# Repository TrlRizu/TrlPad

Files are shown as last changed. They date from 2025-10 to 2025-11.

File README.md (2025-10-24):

# TrlPad

TrlPad is a 4-key macropad with a rotary encoder, an OLED display.

## Features

- 4 programmable mechanical keys (MX-style switches)
- Rotary encoder with push-button for multi-function input
- 0.91" 128x32 OLED dispvlay (SSD1306)
- Powered by Seeed Studio XIAO nRF52840 (Bluetooth + USB)
- Custom PCB

## How it evolved

### The initial concept
The design concept was to be something akin to a pedal effect. A sketch of what I thought it'd be:



### Final
Yeah, it's rather different but this is more feasible and it's simple yet punk-y.



### PCB
Below is the schematic:

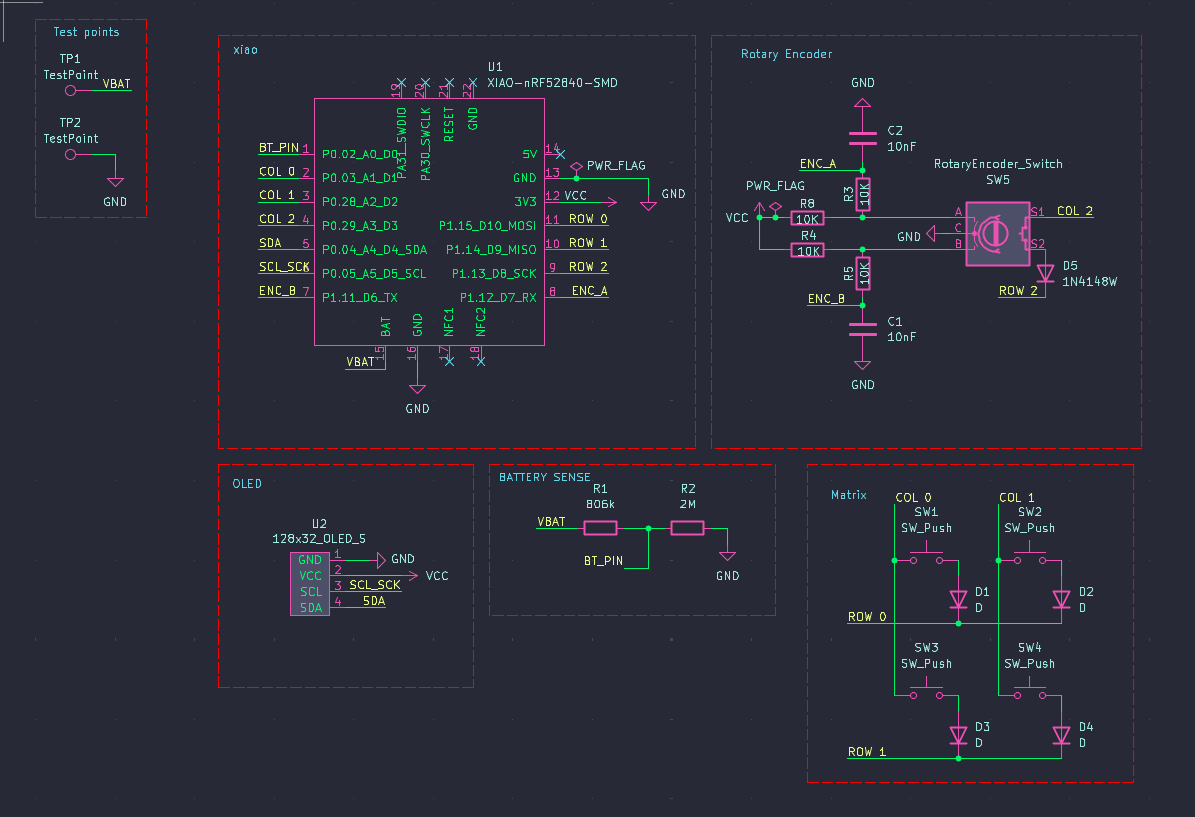
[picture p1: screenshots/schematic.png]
Schematic


Below is the PCB routing:

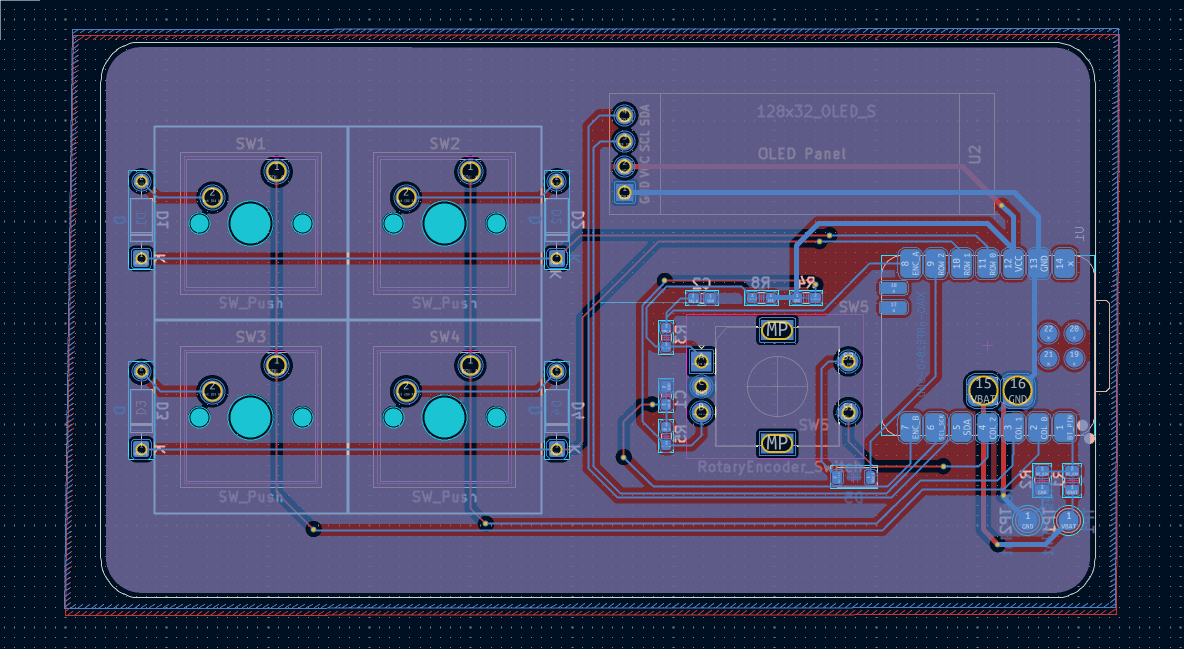
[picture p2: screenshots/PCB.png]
routing

---

## Bill of Materials (BOM)

| #  | Reference | Value | Footprint | Qty | Link | Price (USD) | Running Price (USD) |
|----|---|---|---|-----|---|---|---|
| 1  | D1, D2, D3, D4 | D | Diode_THT:D_DO-35_SOD27_P7.62mm_Horizontal | 4 | [AliExpress](https://www.aliexpress.com/item/1005007625866819.html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) | 1.41 | 1.41 |
| 2  | D5 | 1N4148W | Diode_SMD:D_SOD-123 | 1 | [AliExpress](https://www.aliexpress.com/item/1005007160279747.html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) | 1.95 | 3.36 |
| 3  | R1 | 806k | Resistor_SMD:R_0805_2012Metric | 1 | [AliExpress](https://www.aliexpress.com/item/1005008964311488.html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) | 0.66 | 4.50 |
| 4  | R2 | 2M | Resistor_SMD:R_0805_2012Metric | 1 | [AliExpress](https://www.aliexpress.com/item/1005008964311488.html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) | 0.48 | 4.50 |
| 5  | SW1, SW2, SW3, SW4 | SW_Push | Button_Switch_Keyboard:SW_Cherry_MX_1.00u_PCB  | 4 | [AliExpress](https://www.aliexpress.com/item/1005006255961111.html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) | 1.01 | 5.51 |
| 6  | SW5 | RotaryEncoder_Switch | Rotary_Encoder:RotaryEncoder_Alps_EC11E-Switch_Vertical_H20mm | 1 | [AliExpress](https://www.aliexpress.com/item/1005006693443387.html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) | 0.63 | 6.14 |
| 7  | TP1, TP2 | TestPoint | TestPoint:TestPoint_Pad_D2.0mm | 2 | — | — | 6.14 |
| 8  | U1 | XIAO-nRF52840-SMD  | Modified:modified-XIAO-nRF52840-SMD | 1 | [AliExpress](https://www.aliexpress.com/item/1005006988954136.html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) | 10.11 | 16.25 |
| 9  | U2 | 128x32_OLED_S | zzz_Project:SSD1306-0.91-OLED-4pin-128x32 | 1 | [AliExpress](https://www.aliexpress.com/item/1005008640132638.html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) | 2.24 | 18.49 |
| 10 | Shipping costs  | — | for AliExpress check cart.png | — | — | 3.05 | 21.54 |
| 11 | 3D Printed case | — | check screenshot 3dCase_bill.png | — | [3Ding](https://print.3ding.in/upload) | 16.29 | 37.83 |
| 12 | PCB | — | from JLPCB, check screenshot jlcpcb.png | — | — | 7.56 | 45.39 |

**Total Estimated Cost:** 45.39 USD

####  Note: I am trying to get the case 3D printed using #printing-legion, or if that doesn't work out, I'll cover the cost on my own!
---

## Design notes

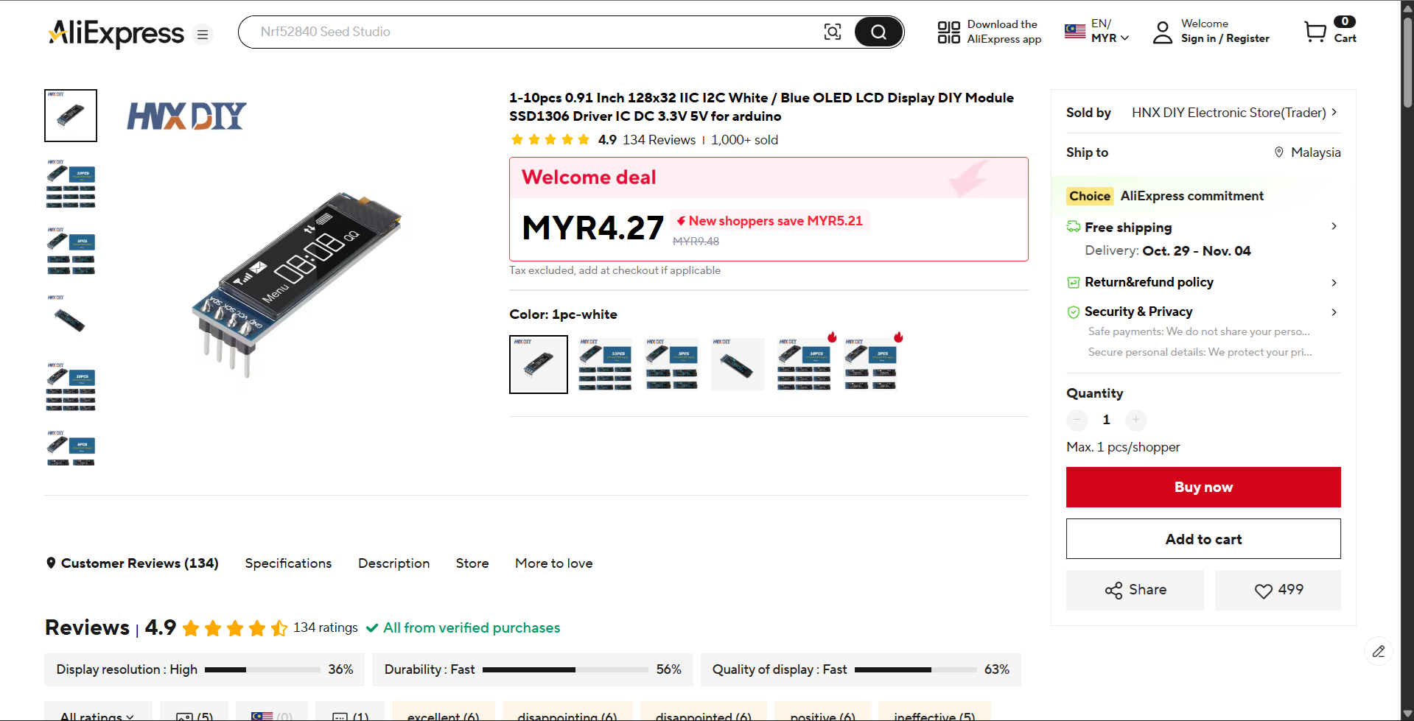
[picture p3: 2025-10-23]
screenshots/oled.png

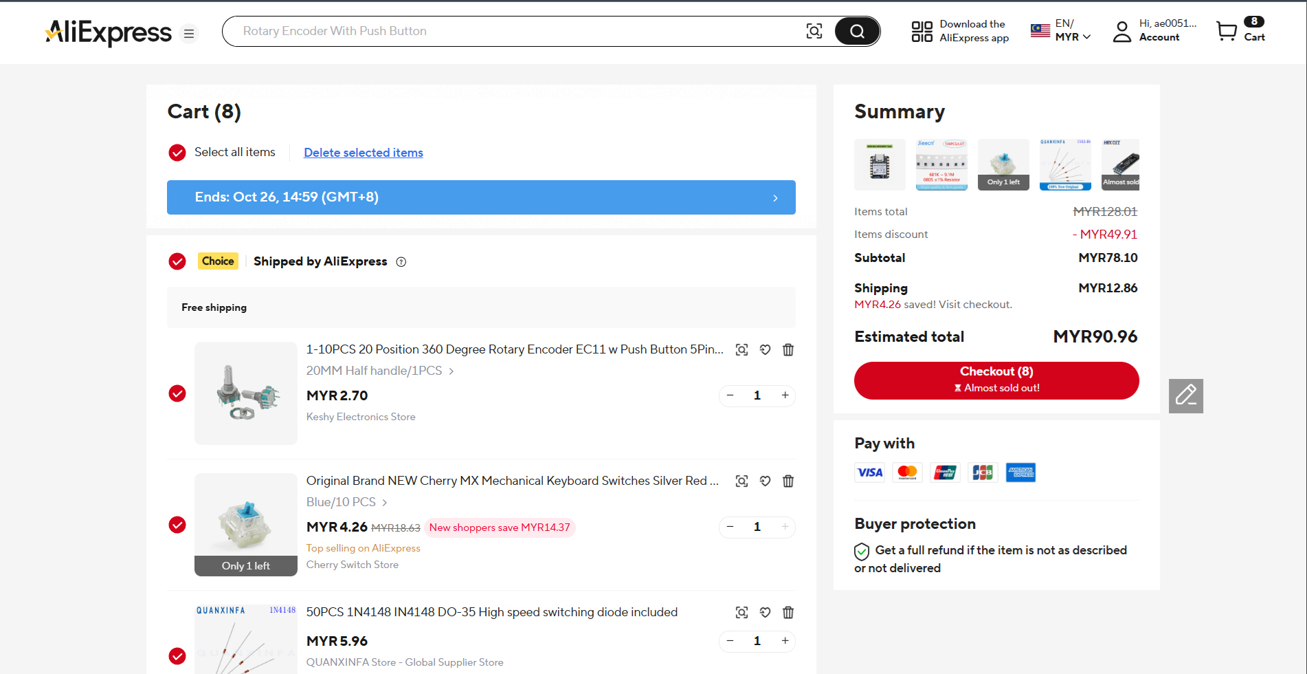
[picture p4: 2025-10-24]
screenshots/cart.png

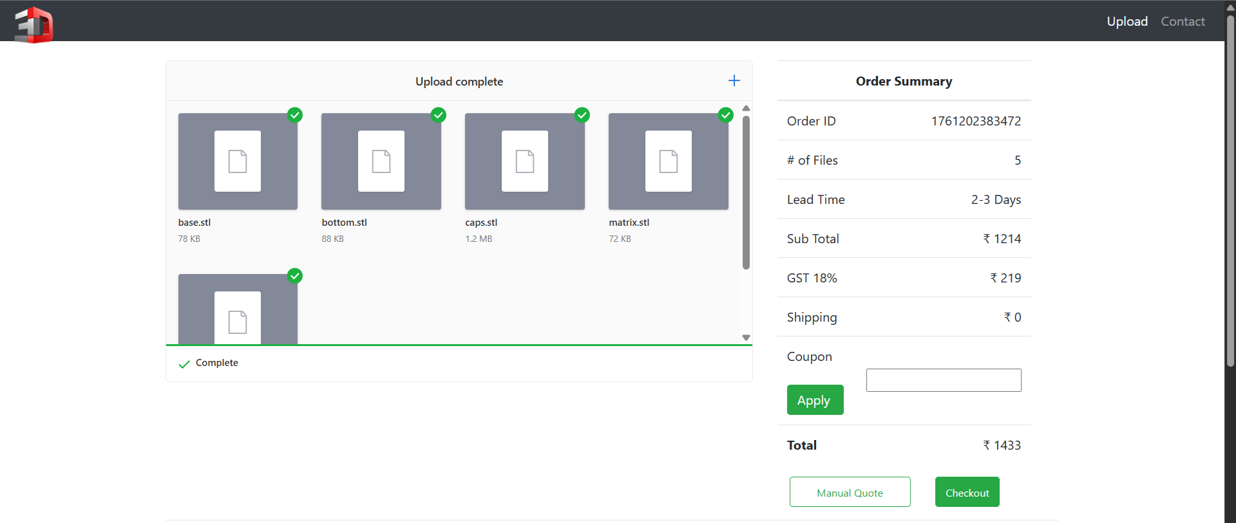
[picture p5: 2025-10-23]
screenshots/3dCase_bill.png

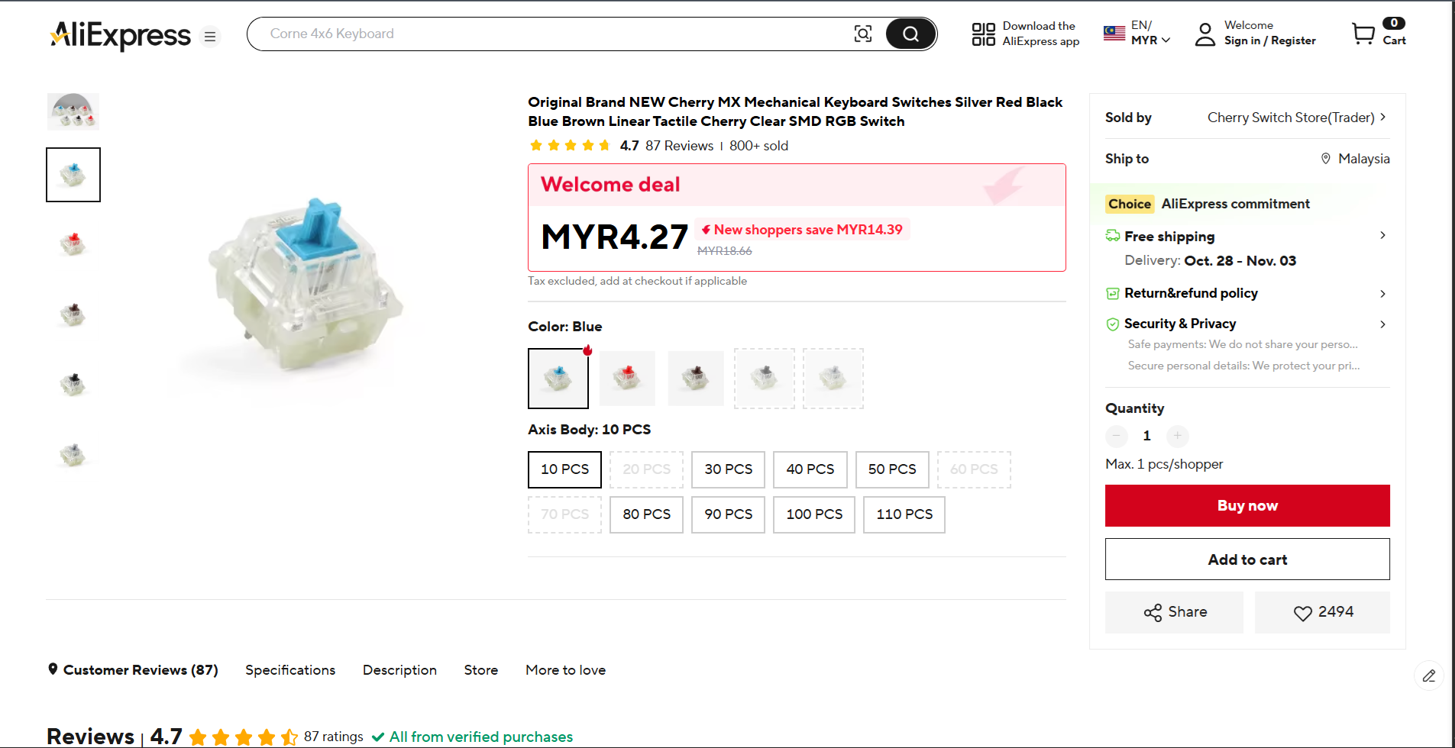
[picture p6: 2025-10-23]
screenshots/cherry-mx.png

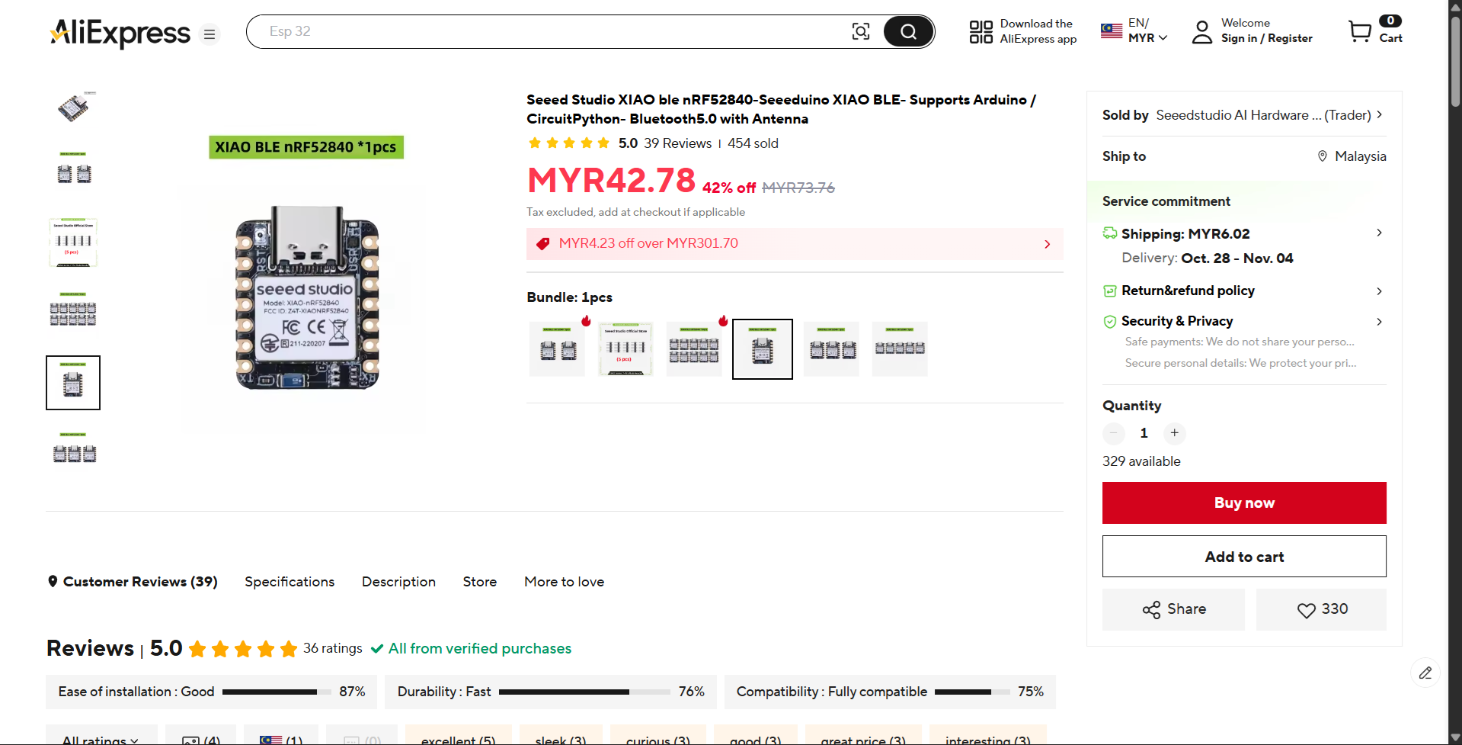
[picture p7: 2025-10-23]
screenshots/xiao.png

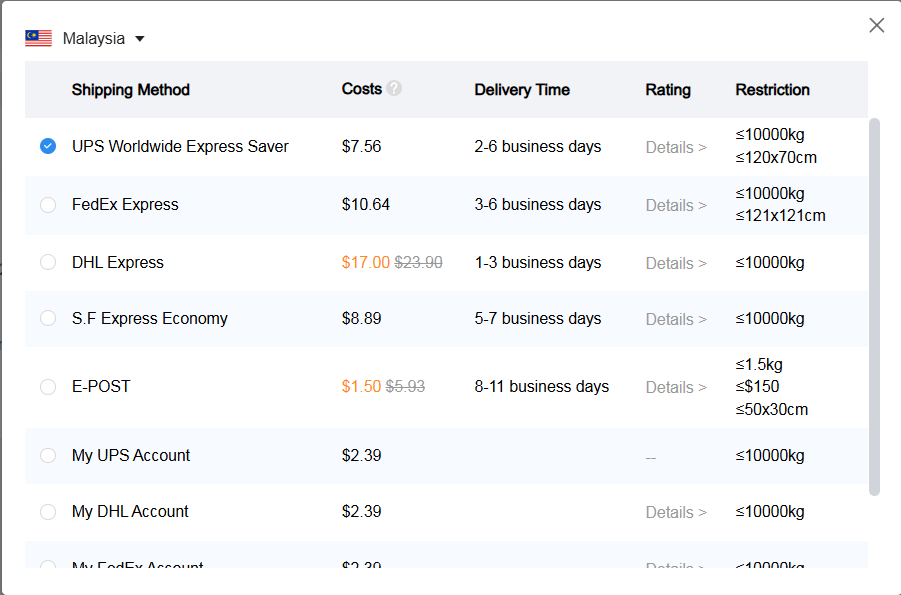
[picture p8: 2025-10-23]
screenshots/shipping.png

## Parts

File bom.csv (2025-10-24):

# | Reference | Value | Footprint | Qty | Link | Price | Running Price
1 | D1,D2,D3,D4 | D | Diode_THT:D_DO-35_SOD27_P7.62mm_Horizontal | 4 | https://www.aliexpress.com/item/1005007625866819.html | 1.41 | 1.41
2 | D5 | 1N4148W | Diode_SMD:D_SOD-123 | 1 | https://www.aliexpress.com/item/1005007160279747.html | 1.95 | 3.36
3 | R1 | 806k | Resistor_SMD:R_0805_2012Metric | 1 | https://www.aliexpress.com/item/1005008964311488.html | 0.66 | 4.5
4 | R2 | 2M | Resistor_SMD:R_0805_2012Metric | 1 | https://www.aliexpress.com/item/1005008964311488.html | 0.48 | 4.5
5 | SW1,SW2,SW3,SW4 | SW_Push | Button_Switch_Keyboard:SW_Cherry_MX_1.00u_PCB | 4 | https://www.aliexpress.com/item/1005006255961111.html | 1.01 | 5.51
6 | SW5 | RotaryEncoder_Switch | Rotary_Encoder:RotaryEncoder_Alps_EC11E-Switch_Vertical_H20mm | 1 | https://www.aliexpress.com/item/1005006693443387.html | 0.63 | 6.14
7 | TP1,TP2 | TestPoint | TestPoint:TestPoint_Pad_D2.0mm | 2
8 | U1 | XIAO-nRF52840-SMD | Modified:modified-XIAO-nRF52840-SMD | 1 | https://www.aliexpress.com/item/1005006988954136.html | 10.11 | 16.25
9 | U2 | 128x32_OLED_S | zzz_Project:SSD1306-0.91-OLED-4pin-128x32 | 1 | https://www.aliexpress.com/item/1005008640132638.html | 2.24 | 18.49
10 | Shipping costs |  | for AliExpress check cart.png |  |  | 3.05 | 21.54
11 | 3D Printed case |  | check screenshot 3dCase_bill.png |  | https://print.3ding.in/upload | 16.29 | 37.83
12 | PCB |  | from JLPCB, check screenshot jlcpcb.png |  |  | 7.56 | 45.39
 | Total |  |  |  |  |  | 45.39

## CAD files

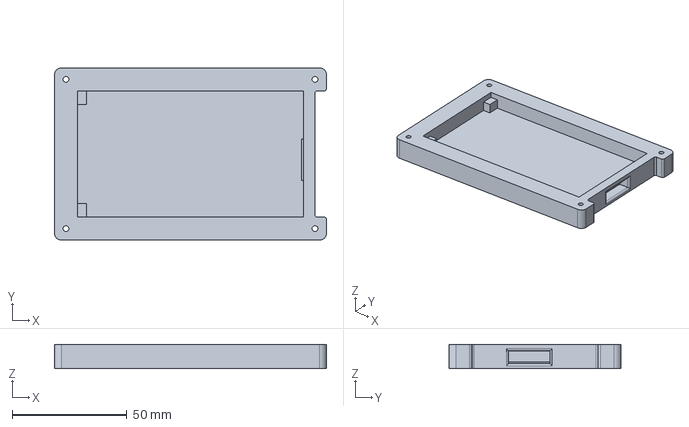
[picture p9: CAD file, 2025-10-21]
case/base.step
118.5 x 75.0 x 10.6 mm

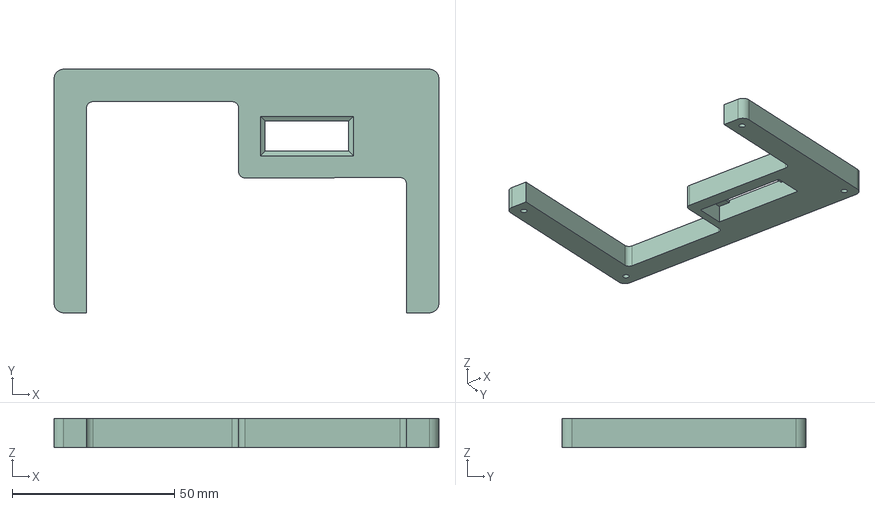
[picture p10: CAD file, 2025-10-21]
case/overlay.step
118.5 x 75.0 x 9.00 mm

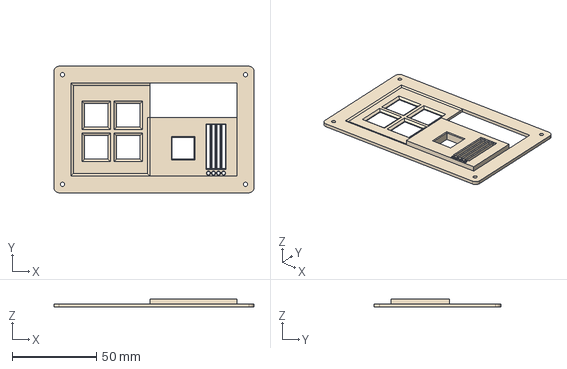
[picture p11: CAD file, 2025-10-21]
case/matrix.step
118.5 x 75.0 x 5.00 mm

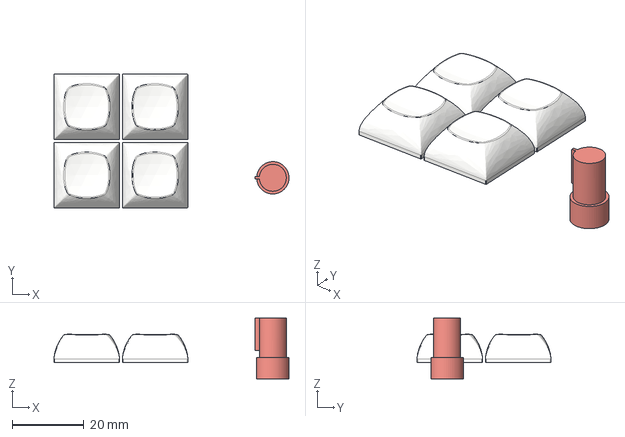
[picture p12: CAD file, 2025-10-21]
case/caps.step
65.3 x 37.2 x 16.9 mm
MX Mount v1 x 4
rotary

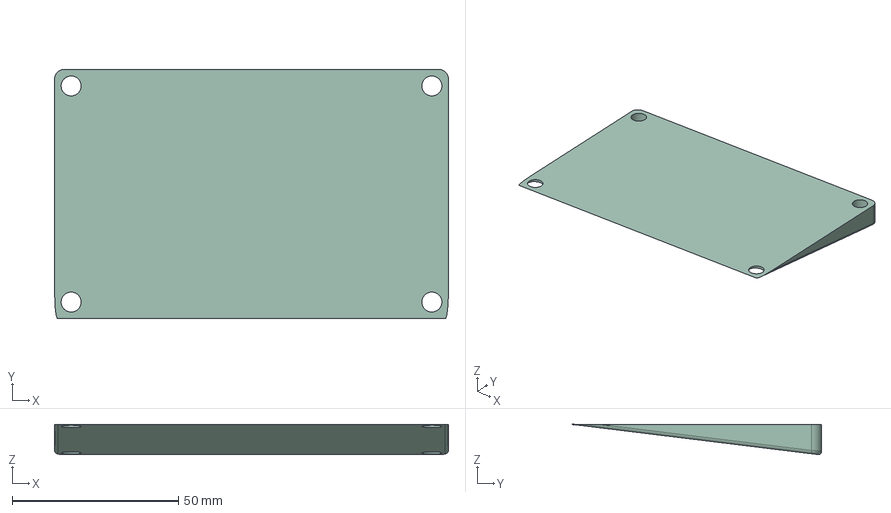
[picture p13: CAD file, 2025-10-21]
case/bottom.step
118.5 x 75.0 x 9.08 mm

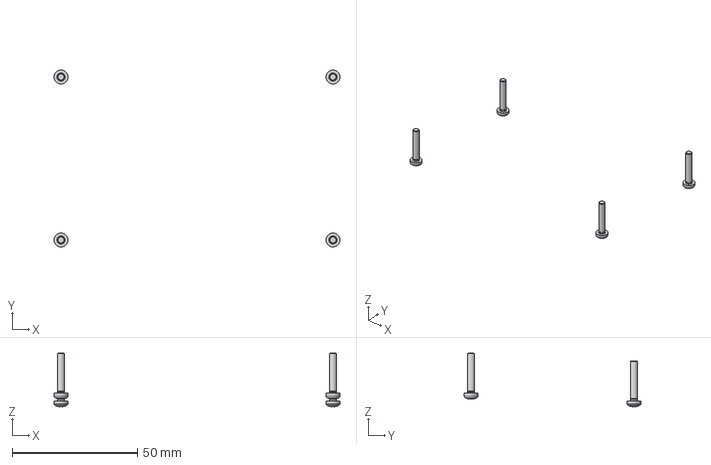
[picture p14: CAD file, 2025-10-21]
case/screws.step
114.1 x 70.6 x 21.5 mm
ISO 7045 - M3 x 16 - Z Steel 4.6 Plain x 4

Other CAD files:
case/stl/base.stl
case/stl/bottom.stl
case/stl/caps.stl
case/stl/matrix.stl
case/stl/overlay.stl

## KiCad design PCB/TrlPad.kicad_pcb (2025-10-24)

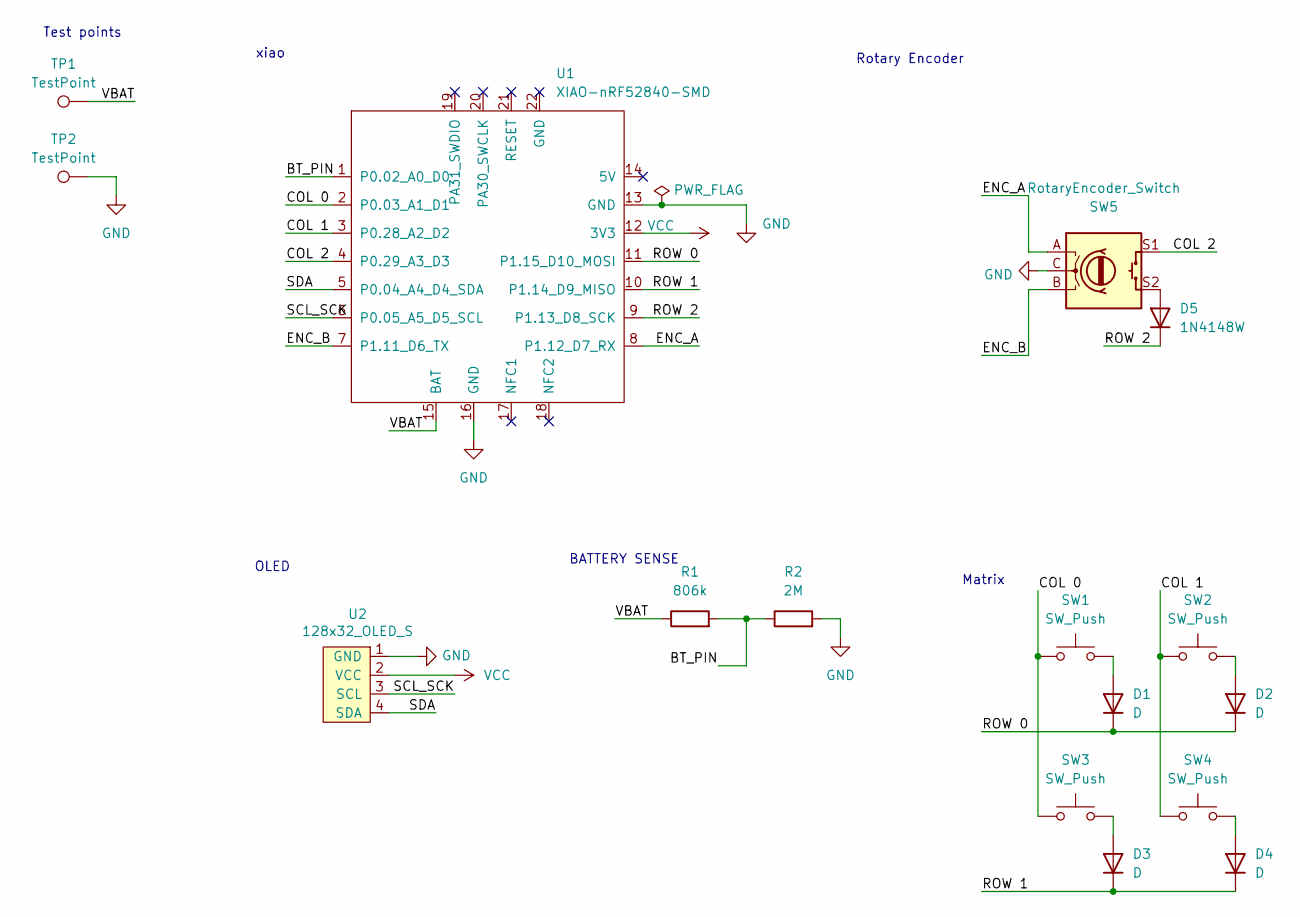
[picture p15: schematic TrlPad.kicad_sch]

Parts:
D1, D2, D3, D4: D; D_DO-35_SOD27_P7.62mm_Horizontal
D5: 1N4148W; D_SOD-123
R1: 806k; R_0805_2012Metric
R2: 2M; R_0805_2012Metric
SW1, SW2, SW3, SW4: SW_Push; SW_Cherry_MX_1.00u_PCB
SW5: RotaryEncoder_Switch; RotaryEncoder_Alps_EC11E-Switch_Vertical_H20mm
TP1, TP2: TestPoint; TestPoint_Pad_D2.0mm
U1: XIAO-nRF52840-SMD; modified-XIAO-nRF52840-SMD
U2: 128x32_OLED_S; SSD1306-0.91-OLED-4pin-128x32

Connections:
/BT_PIN: R1.2, R2.1, U1.1 (P0.02_A0_D0)
/COL 0: SW1.1, SW3.1, U1.2 (P0.03_A1_D1)
/COL 1: SW2.1, SW4.1, U1.3 (P0.28_A2_D2)
/COL 2: SW5.S1, U1.4 (P0.29_A3_D3)
/ENC_A: SW5.A, U1.8 (P1.12_D7_RX)
/ENC_B: SW5.B, U1.7 (P1.11_D6_TX)
/ROW 0: D1.1 (K), D2.1 (K), U1.11 (P1.15_D10_MOSI)
/ROW 1: D3.1 (K), D4.1 (K), U1.10 (P1.14_D9_MISO)
/ROW 2: D5.1 (K), U1.9 (P1.13_D8_SCK)
/SCL_SCK: U1.6 (P0.05_A5_D5_SCL), U2.3 (SCL)
/SDA: U1.5 (P0.04_A4_D4_SDA), U2.4 (SDA)
/VBAT: R1.1, TP1.1, U1.15 (BAT)
GND: R2.2, SW5.C, TP2.1, U1.13 (GND), U1.16 (GND), U2.1 (GND)
unnamed: D1.2 (A), SW1.2
unnamed: D2.2 (A), SW2.2
unnamed: D3.2 (A), SW3.2
unnamed: D4.2 (A), SW4.2
unnamed: D5.2 (A), SW5.S2
VCC: U1.12 (3V3), U2.2 (VCC)

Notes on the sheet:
OLED
Rotary Encoder
Test points
BATTERY SENSE
Matrix
xiao

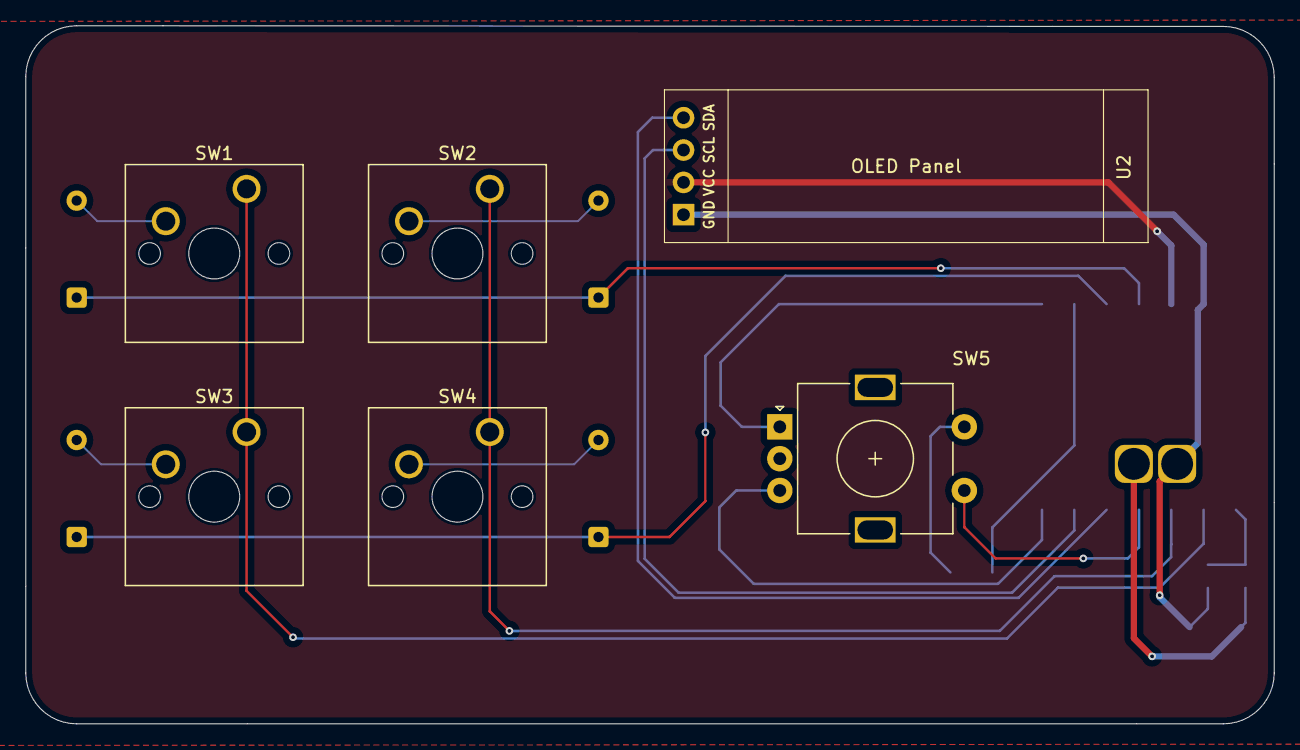
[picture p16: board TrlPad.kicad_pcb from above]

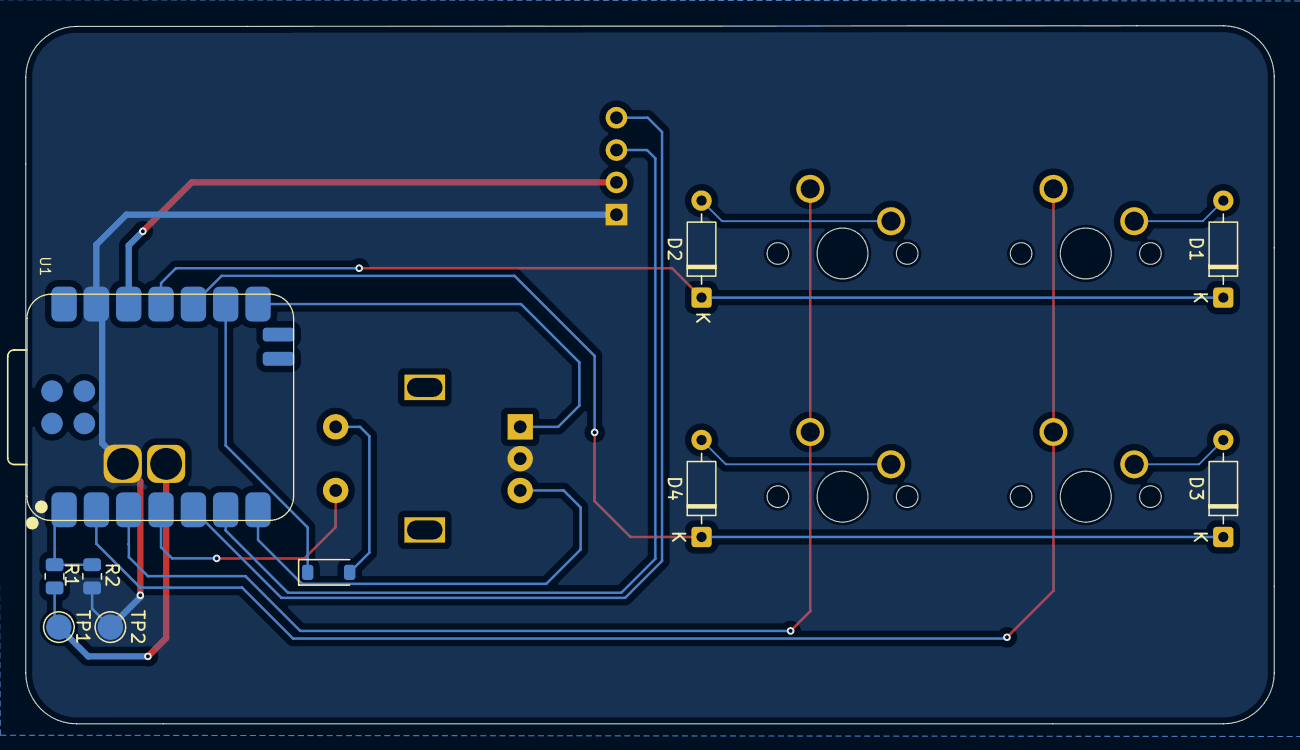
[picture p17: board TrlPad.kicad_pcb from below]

Board: 2 copper layers, 98.1 x 54.8 mm, 16 parts (10 on the bottom side), 19 nets.

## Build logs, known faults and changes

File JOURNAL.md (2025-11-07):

<!--
  ===================    !!READ THIS NOTICE!!   ====================
  DO NOT edit this file manually. Your changes WILL BE OVERWRITTEN!
  This journal is auto generated and updated by Hack Club Blueprint.
  To edit this file, please edit your journal entries on Blueprint.
  ==================================================================
-->

## 10/11/2025 - Followed the tutorial  

This marks the start of my macropad. First time doing electronics. Special thanks to nimit and other people in the thread for encouraging me! They also suggested that I needed a deskop app. But for the hardware, the vision would something be like below:



Details: a macropad with 4 keys, rotary encoder and an OLED screen up top. The design inspiration was drawn from effect pedals (it alters sound of a musical instrument, seen them being used by friends and thought it looked cool). 

This isn’t my first time using KiCAD, but it's the first project I’m turning into a real, functioning PCB. Even so, I followed the tutorial from [hackpad](https://hackpad.hackclub.com/guide) to learn from the best, since I’m still a novice.

I had troubles importing the footprint, it didn't detect the imported library automatically. I had to manually select the footprint by double-clicking the component in the schematic editor. After checking with DRC, there appeared to be numerous warnings which I was told by hack-clubbers to ignore apart from the line-height. I patched things up.





I shall begin my actual schematic prototyping in the next journal!

## 10/14/2025 - Schematic drafting  

I re-thought the parts I was going to use for this project. It felt that the xiao nrf52840 was more suitable as the guide said it "has wireless capabilities". For some reason again, there were problems with my library imports- I had to install and uninstall, reboot the application a couple times before I could see the footprint.

I spent most of my time researching rotary encoders and the possibility of it being connected with my keyboard matrix. I found some solutions but I am quite puzzled, frankly lost, in their PCB schematics. I made little progress with the project itself as today's work was more researching and asking. 



## 10/15/2025 - Polishing schematic + Learning lots  

Continued with research: reading blogs regarding rotary encoder, examining the pcb of the split keyboard guide to figure out where the placements of the 'battery sense' and 'test points' should be, why it's important to use a 4-pin only OLED display etc. 

I also asked around why the Resistor values were the way they were in battery sense, but I didn't get an answer to that. I knew the formula but why was it precisely those?

Eventually everything started to click when I looked after seeing this [repo](https://github.com/bytesizedengineering/macropad?tab=readme-ov-file) and [this one](https://palmacas.com/macroboard-diseno/) which was a link attached to hackpad tutorial (well sort of). I also discovered that the xiao seeed was flipped which explained the blue outline colours in the guide compared to what was previously red on my screen: learnt the shortcut 'F'. The keyboard switches, the resistors and capacitors for the rotary encoder had to be flipped too.

I also learnt the difference between SMD diodes and THT diodes, visually at least -THT really does look more beginner-friendly to solder compared to the former. Another thing, I switched my switch keys footprint to mx (previously being choc) for the intent of it being more tactile.





Not everything is polished yet but I'll amend things soon. Off to another session of learning!  

## 10/16/2025 - Routed the PCB  

I opted for a horizontal oriented macro-pad, leaving behind the initial design in mind (I shall revamp my sketches). This came to realization when finding space for the OLED display. The xiao micro-controller has its USB facing sideways too for convenience. When it's assembled I would be able to connect it without the wires going over my laptop keyboard.



Honestly routing only took so long coz I thought of it as a puzzle (y'know that game where you have to connect pipes and that they shouldn't interfere with another). Until, I discovered that I can route through components (thought I'd mess it up by doing that).  

I also added my fill zones! [This](https://wiki.ai03.com/books/pcb-design/chapter/pcb-designer-guide) and Phil's lab's vid on it proved very useful. 



Oh shocks...I just realized, are my keypads not facing me?  

## 10/17/2025 - PCB edits + 3D model Research  



Finally, I fixed the switch keys -it now is on the front copper. Below is the alleged PCB that I worked on for the past couple days: 



I then started to think about the design of my macropad. I've searched a YT vid going through the basics of [fusion 360](https://www.youtube.com/watch?v=WEIpQHWqPVw&list=PLLm7Yjr9z_z07ohtjFGkA5w-j_NMj8B3J) as a refresher. 

Furthermore, I desire to continue the design of a pedal effect, borrowing its rectangular outline and its steep elevation between the pedal and the rotary encoders (for my design that would be between the screen+rotary encoder and the keypads. Here is a first look of the design:



I know I know there's a lot to work on, but I shall work on this 3d model further

## 10/18/2025 - 3D model + PCB rerouting  

I first re-routed my PCB after sending it to a discord channel for review. Apparently I needed to make much of my space since my resistors and capacitors were all cramped up. I had to move them but still keep an efficient design. Below is the newly routed PCB (may still make amendments in the future):



I also realized that my screen wasn't positioned at a nice place so when I began to see my 3D model, instantly I knew it had to be moved I guess by 5-10mm further to the right. But anyways, this is my first preview of the keyboard design.



I decided that it'd be better if it was inclined by 7 degrees (6-12 degrees was the incline height for keyboards according to Google):


I guess majority of my time was spent looking through mx switch, rotary encoder and screen blueprints. My brain was always making quick calculations of the possible height + thinking of clearances. I intentionally did not create a USB-C hole on the side for this yet. I thought that having the 1st prototype model ASAP is the goal for today. The design is for sure not yet final, the character of a pedal effect hasn't taken 'effect' yet.   

## 10/20/2025 - Finalized Case + Re-routed PCB  

I am glad to announce that I am almost finished!

I pushed the rotary encoder further down:


I addressed the USB port being blocked by the case, it took a while to find the dimensions of the USB type-C. I borrowed some made-cases online however they were made of surface mesh which wasn't compatible with my design. Eventually I found a work-around (lazily). I imported the STEP file of the PCB with the mounted 3D models and from there began to build my USB port.

However more problems arose with this approach. Then so, I decided I was going to build this from the ground up. I started from scratch, built the base, the inclined bottom, the cover for the keyboard matrix and then the screen overlay. The screws still seem to be a problem tho.. I really need help with that.




## 10/21/2025 - Finished 3D Model  

I finally am done with my case along with the keycaps and rotary encoder case. I copied the keycaps model directly from Orpheuspad credits to the project!



I think I am quite satisfied with my first build. I don't want to over-engineer things and this model is simple yet punk-y enough!  

## 10/23/2025 - BOM  

HI, I'm excited for this to be shipped. I finalized my bom.csv and README.md. I looked through AliExpress for parts and JLCPCB for PCB quotes. I am experiencing some troubles with 3D printing though, not sure where I'd be getting that for my case. I explored the option of #printing-legion as suggested but they're all way too far from where I am. If that doesn't work out I guess, I'll try to source a 3D printing shop or friends and I'll cover the cost on my own. But so far as I've checked with 3D-ing(?) website, it would cost $16? I would definitely want it to be lower since it's not that complicated of a model. Below is a picture attached:

[cost](screenshots/3dCase_bill.png) 

but overall this was my BOM


## 10/24/2025 - Updated PCB  

Hello I updated my PCB, removed the passive capacitors and resistors connected to the rotary encoder!





Apart from that somebody from printing legion can in fact help me! So it was quoted that the shipping cost would be $12-$17? I think that should be still under our given grant of $45?  

## 11/8/2025 - Blinked My First LED  

I used the built-in RGB LED in the XIAO SEEED ESP32-NRF52840

I created a program that made it blink alternately, very simple but I also explored the possible ways I can make my firmware for the Macropad. I'll discuss it below, but here are some pics:




## Application: 
Python-side
- Tkinter (GUI) 
- Reads battery percentage (psutil) and Spotify info (spotipy).
- Combines data into a string (e.g., "85|Song Name|Artist Name\n").
- Sends the string over the USB serial port to ESP32.
- Packaged by PyInstaller
ESP32-side
- Reads incoming serial data.
- Parses string into battery, song, and artist.
- Updates OLED display accordingly.

I also just realized how tiny the OLED display is, will make it condensed yet still aesthetic.

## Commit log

2025-10-21 renamed bom
    [bom.csv]
2025-10-23 Updated repo
    [base.stl, bom.csv, bottom.stl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]
2025-10-23 Updated BOM
2025-10-24 Updated BOM + fixed PCB
    [TrlPad.kicad_pcb, TrlPad.kicad_sch, bom.csv]
